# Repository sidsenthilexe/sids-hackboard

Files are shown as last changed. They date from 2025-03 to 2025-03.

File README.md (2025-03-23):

# Sid's Hackboard
My hackboard is pretty closely based on my current keyboard (Steelseries Apex 3 TKL) because it fits very well for what I need it to do. Probably could have optimized it more but ran out of time.                         
I'll probably make some keys macros especially the cluster around Delete.                   
It also includes a volume knob + a switch for play/pause, skip, and rewind.                         
This was actually way easier than hackpad because I now use KiCad and Fusion a lot more (even for other projects), but figuring out how to do the integrated plate was a bit annoying, and drafting the edges also took some figuring out.                      
Anyway I made a (hopefully) functional keyboard.                    

## Key Features:
* Standard TKL layout
* Plate with integrated case
* Magnetic lift bar - totally not copied from s76
* Volume knob
* Probably way too tall but I didn't bother to measure properly

## CAD/case:
M3 (M5? idek) bolts and heatset inserts are used to hold the 2 pieces together, and an integrated plate is used to hold the pcb.

## PCB:
A matrix is wired to prevent ghosting - the wiring took way too long. There are 84 total keys and one rotary encoder + switch, organized in 17 columns and 6 rows.

## Firmware:
KMK was used for the firmware, I still need to figure out how to implement the volume controls though.

## BOM:
|ITEM|QTY|PRICE|
|----|---|-----|
|Orpheus Pico|1|price|
|mx switches|qty|price|
|stabs|qty|price|
|encoder|qty|price|
|3x10x60mm Magnets|1 pack of 4|5.99|
|1N4148 diodes|qty|price|
|keycaps|qty|price|
|bolts|qty|price|
|heatset inserts|qty|price|

## Images:
Fully assembled:          
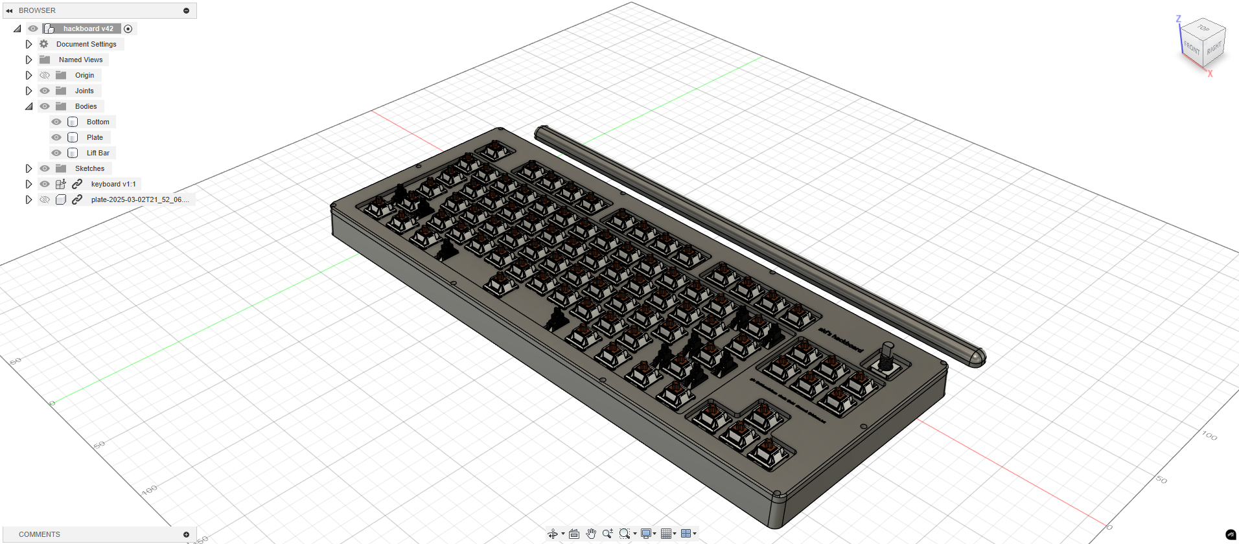
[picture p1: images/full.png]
               
Schematic:          
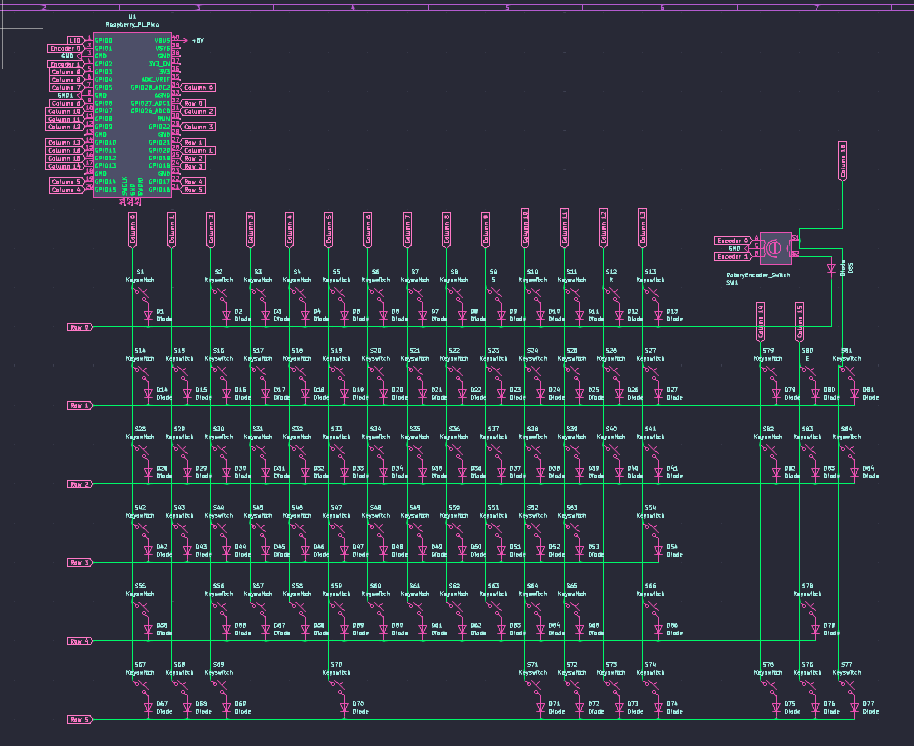
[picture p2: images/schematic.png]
                           
PCB:            
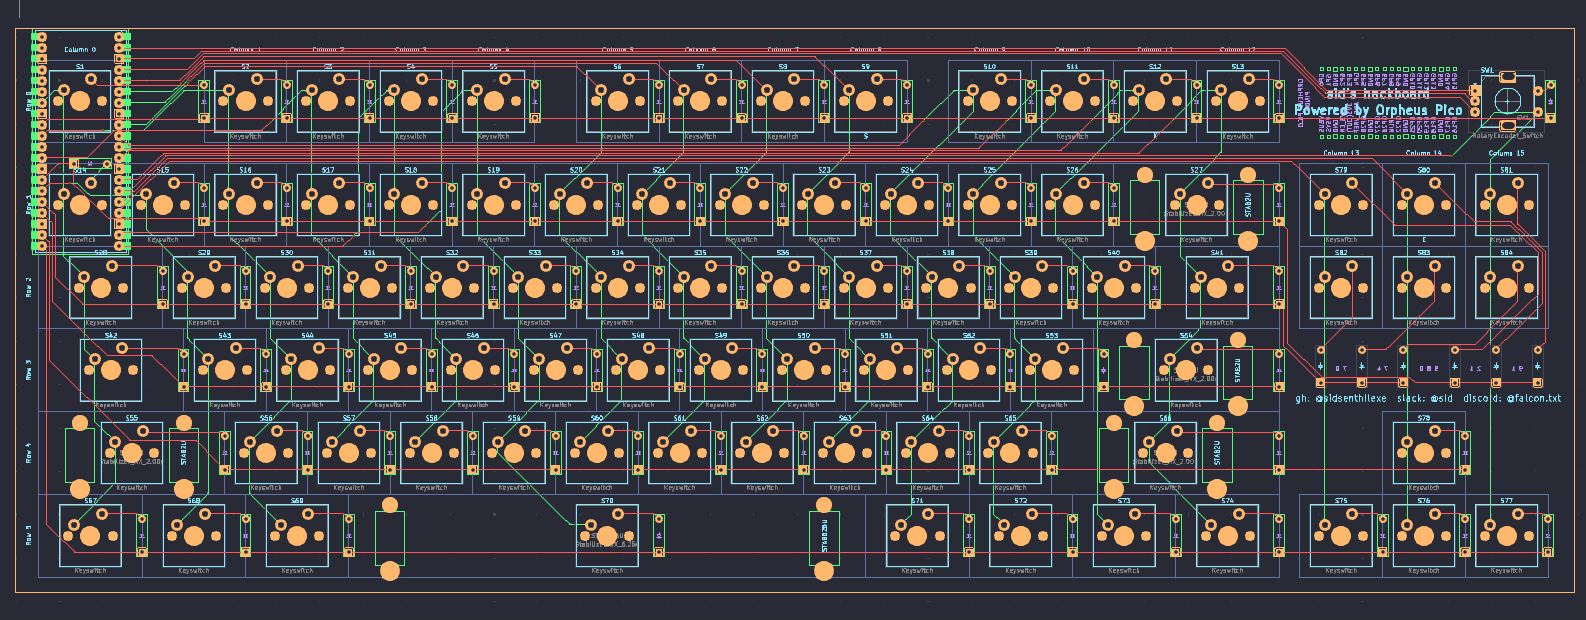
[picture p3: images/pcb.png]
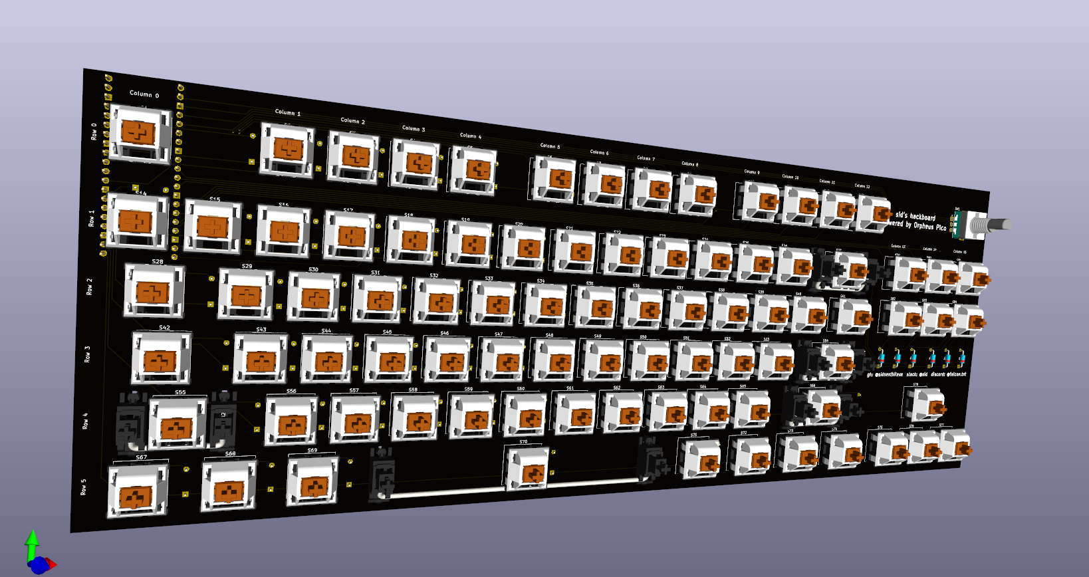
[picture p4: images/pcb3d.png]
                                                   
Case:                                                     
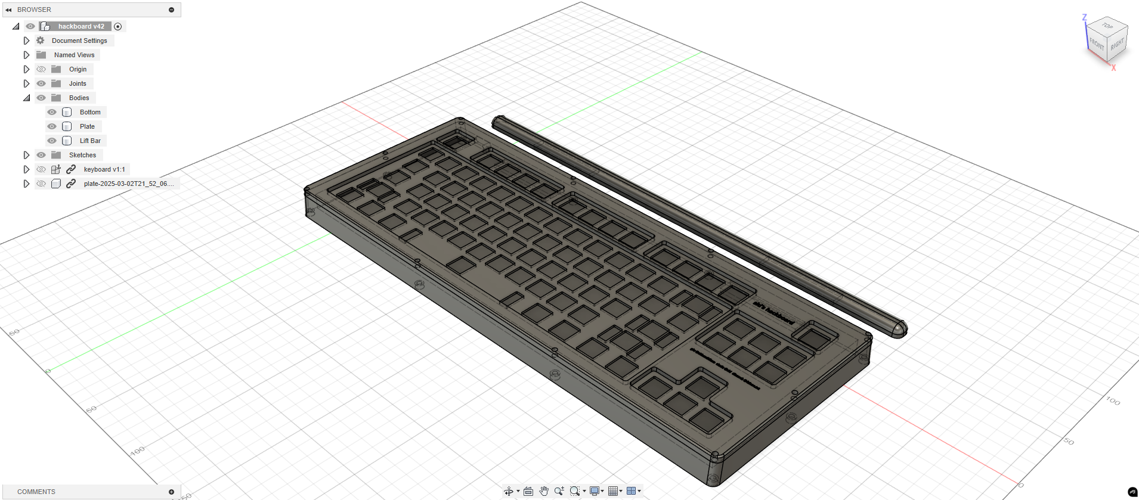
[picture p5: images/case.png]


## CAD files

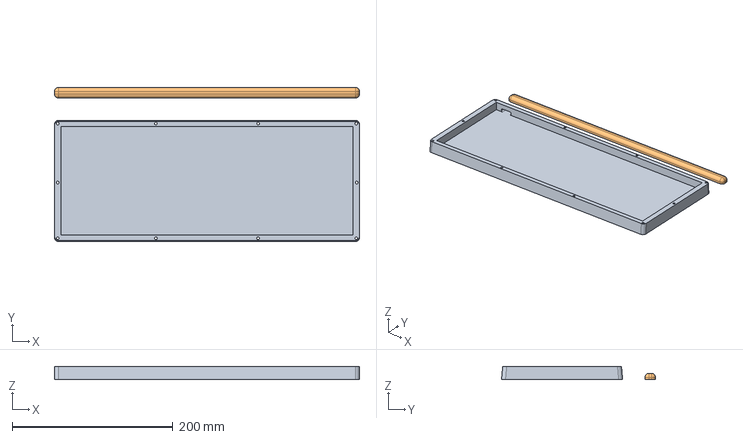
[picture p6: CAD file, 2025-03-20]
production/bottom_lift_bar.step
380.0 x 191.9 x 16.8 mm

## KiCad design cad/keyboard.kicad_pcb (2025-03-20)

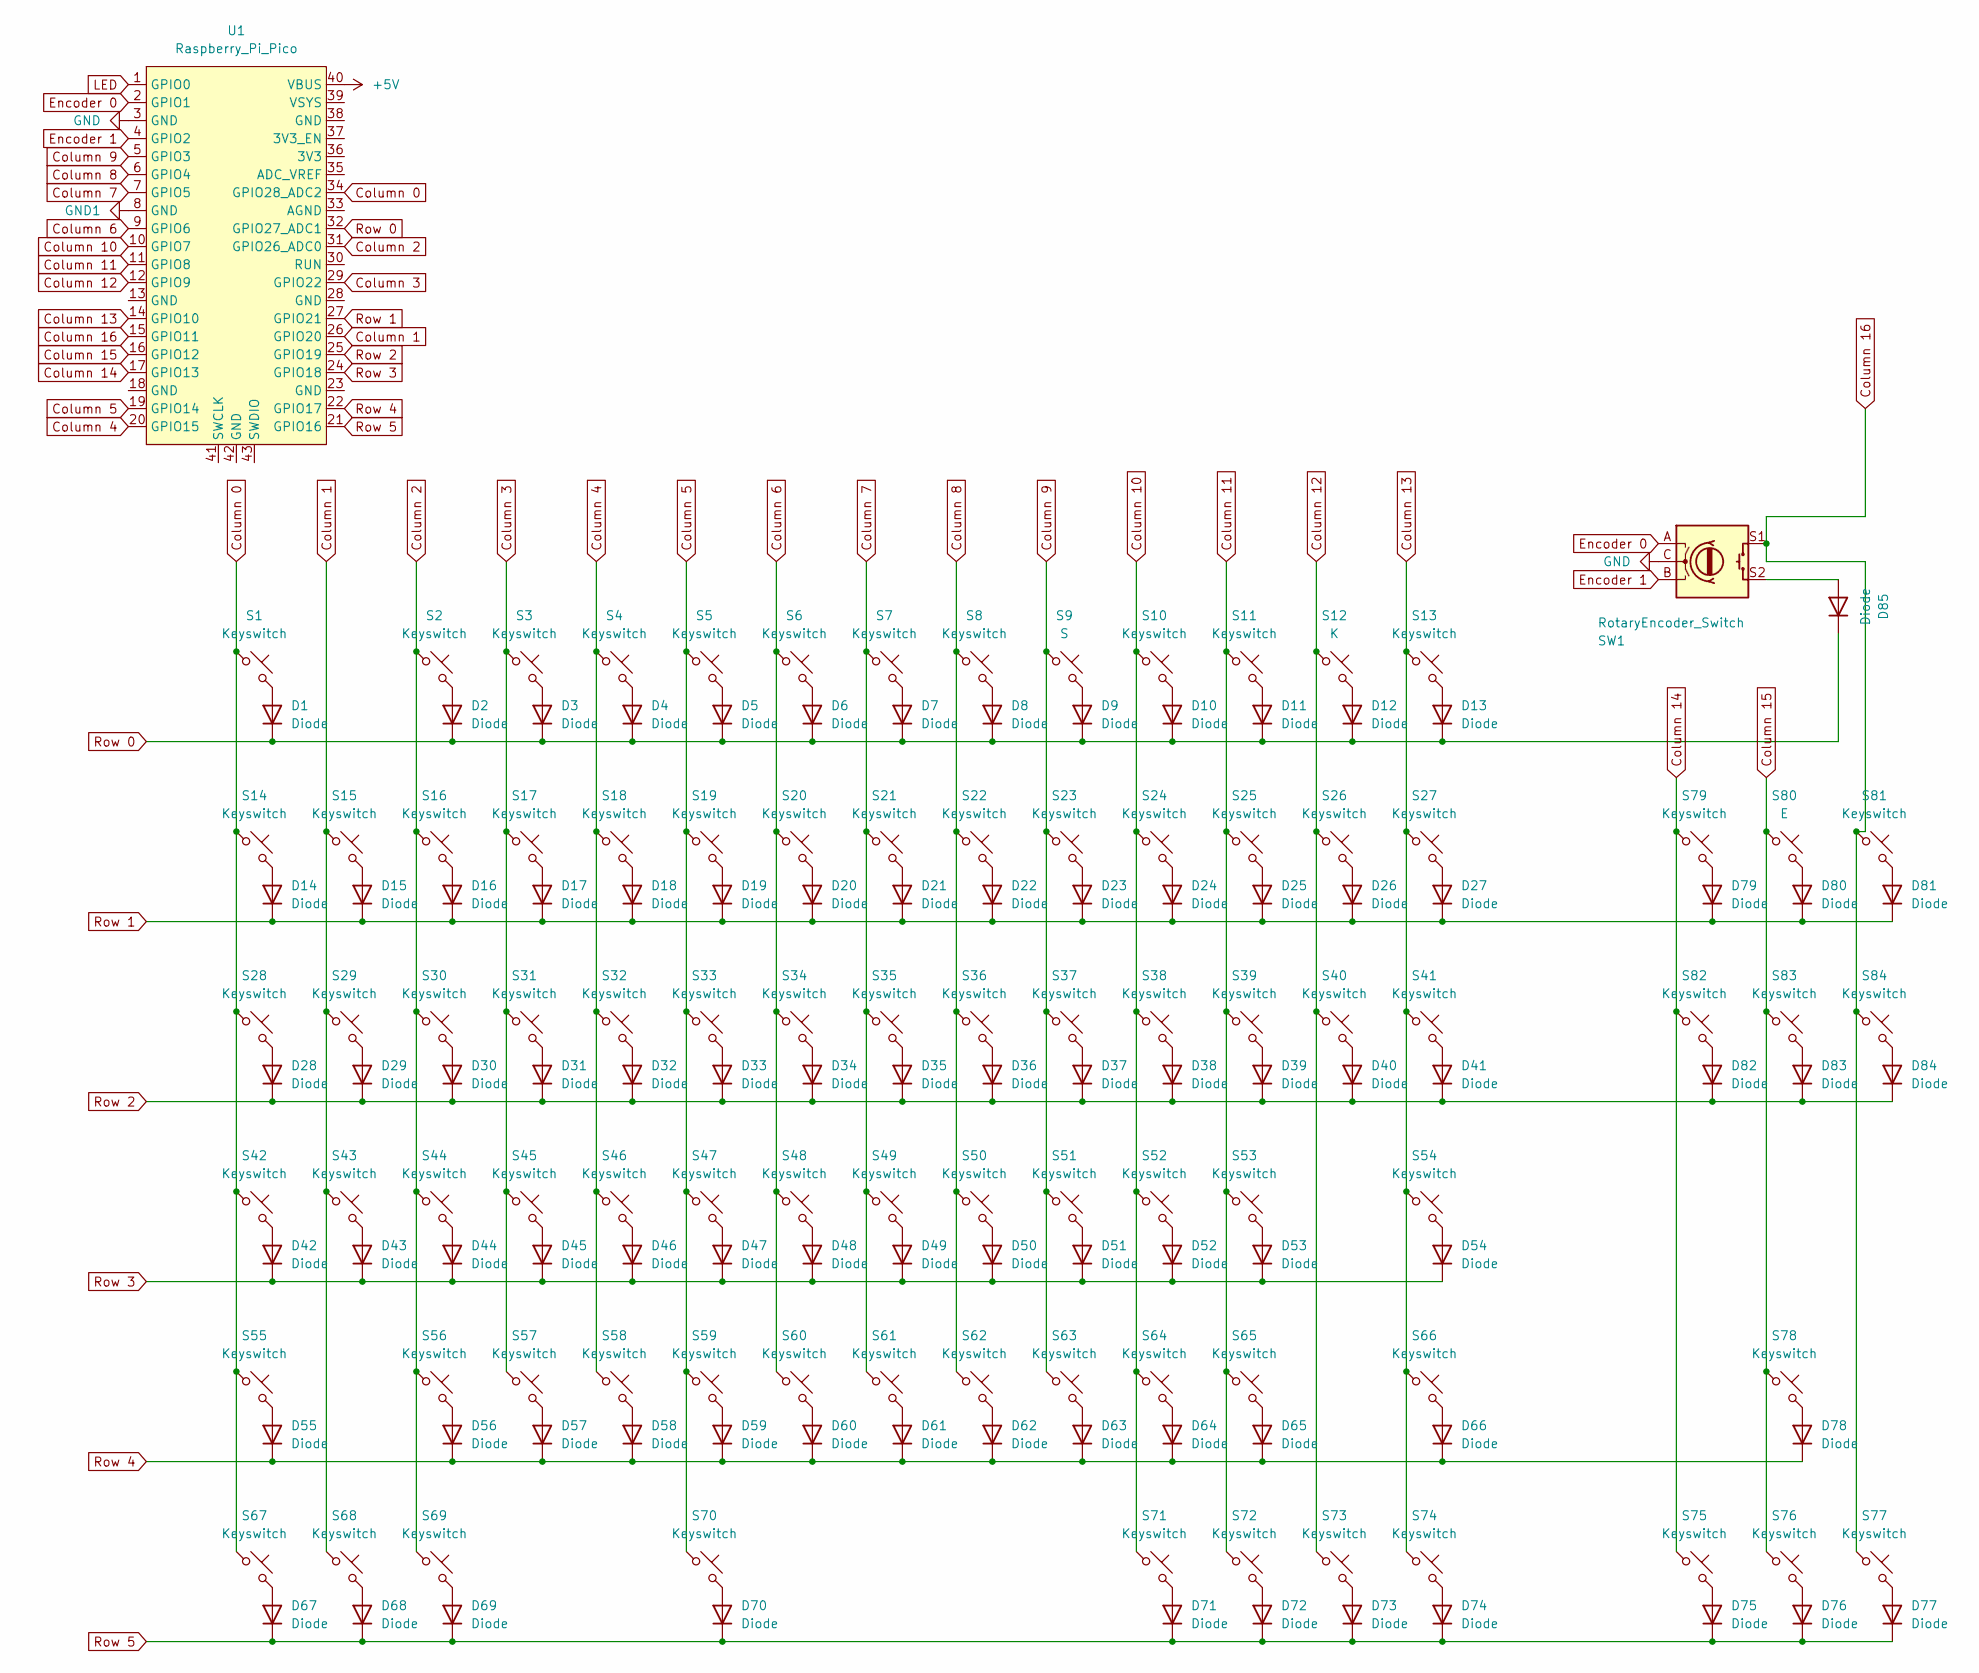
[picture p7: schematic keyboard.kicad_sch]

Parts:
D1, D2, D3, D4, D5, D6, D7, D8, D9, D10, D11, D12, D13, D14, D15, D16, D17, D18, D19, D20, D21, D22, D23, D24, D25, D26, D27, D28, D29, D30, D31, D32, D33, D34, D35, D36, D37, D38, D39, D40, D41, D42, D43, D44, D45, D46, D47, D48, D49, D50, D51, D52, D53, D54, D55, D56, D57, D58, D59, D60, D61, D62, D63, D64, D65, D66, D67, D68, D69, D70, D71, D72, D73, D74, D75, D76, D77, D78, D79, D80, D81, D82, D83, D84, D85: Diode; Diode_DO-35
S1, S2, S3, S4, S5, S6, S7, S8, S10, S11, S13, S14, S15, S16, S17, S18, S19, S20, S21, S22, S23, S24, S25, S26, S29, S30, S31, S32, S33, S34, S35, S36, S37, S38, S39, S40, S43, S44, S45, S46, S47, S48, S49, S50, S51, S52, S53, S56, S57, S58, S59, S60, S61, S62, S63, S64, S65, S75, S76, S77, S78, S79, S81, S82, S83, S84: Keyswitch; MX_PCB_1.00u
S9: S; MX_PCB_1.00u
S12: K; MX_PCB_1.00u
S27: Keyswitch; MX_PCB_2.00u
S28, S41: Keyswitch; MX_PCB_1.50u
S42: Keyswitch; MX_PCB_1.75u
S54, S55: Keyswitch; MX_PCB_2.25u
S66: Keyswitch; MX_PCB_2.75u
S67, S68, S69, S71, S72, S73, S74: Keyswitch; MX_PCB_1.25u
S70: Keyswitch; MX_PCB_6.25u
S80: E; MX_PCB_1.00u
SW1: RotaryEncoder_Switch; RotaryEncoder_Alps_EC11E-Switch_Vertical_H20mm
U1: Raspberry_Pi_Pico

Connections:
+5V: U1.40 (VBUS)
Column 0: S1.1, S14.1, S28.1, S42.1, S55.1, S67.1, U1.34 (GPIO28_ADC2)
Column 1: S15.1, S29.1, S43.1, S68.1, U1.26 (GPIO20)
Column 2: S2.1, S16.1, S30.1, S44.1, S56.1, S69.1, U1.31 (GPIO26_ADC0)
Column 3: S3.1, S17.1, S31.1, S45.1, S57.1, U1.29 (GPIO22)
Column 4: S4.1, S18.1, S32.1, S46.1, S58.1, U1.20 (GPIO15)
Column 5: S5.1, S19.1, S33.1, S47.1, S59.1, S70.1, U1.19 (GPIO14)
Column 6: S6.1, S20.1, S34.1, S48.1, S60.1, U1.9 (GPIO6)
Column 7: S7.1, S21.1, S35.1, S49.1, S61.1, U1.7 (GPIO5)
Column 8: S8.1, S22.1, S36.1, S50.1, S62.1, U1.6 (GPIO4)
Column 9: S9.1, S23.1, S37.1, S51.1, S63.1, U1.5 (GPIO3)
Column 10: S10.1, S24.1, S38.1, S52.1, S64.1, S71.1, U1.10 (GPIO7)
Column 11: S11.1, S25.1, S39.1, S53.1, S65.1, S72.1, U1.11 (GPIO8)
Column 12: S12.1, S26.1, S40.1, S73.1, U1.12 (GPIO9)
Column 13: S13.1, S27.1, S41.1, S54.1, S66.1, S74.1, U1.14 (GPIO10)
Column 14: S75.1, S79.1, S82.1, U1.17 (GPIO13)
Column 15: S76.1, S78.1, S80.1, S83.1, U1.16 (GPIO12)
Column 16: S77.1, S81.1, S84.1, SW1.S1, U1.15 (GPIO11)
Encoder 0: SW1.A, U1.2 (GPIO1)
Encoder 1: SW1.B, U1.4 (GPIO2)
GND: SW1.C, U1.3 (GND)
GND1: U1.8 (GND)
LED: U1.1 (GPIO0)
unnamed: D1.2 (A), S1.2
unnamed: D2.2 (A), S2.2
unnamed: D3.2 (A), S3.2
unnamed: D4.2 (A), S4.2
unnamed: D5.2 (A), S5.2
unnamed: D6.2 (A), S6.2
unnamed: D7.2 (A), S7.2
unnamed: D8.2 (A), S8.2
unnamed: D9.2 (A), S9.2
unnamed: D10.2 (A), S10.2
unnamed: D11.2 (A), S11.2
unnamed: D12.2 (A), S12.2
unnamed: D13.2 (A), S13.2
unnamed: D14.2 (A), S14.2
unnamed: D15.2 (A), S15.2
unnamed: D16.2 (A), S16.2
unnamed: D17.2 (A), S17.2
unnamed: D18.2 (A), S18.2
unnamed: D19.2 (A), S19.2
unnamed: D20.2 (A), S20.2
unnamed: D21.2 (A), S21.2
unnamed: D22.2 (A), S22.2
unnamed: D23.2 (A), S23.2
unnamed: D24.2 (A), S24.2
unnamed: D25.2 (A), S25.2
unnamed: D26.2 (A), S26.2
unnamed: D27.2 (A), S27.2
unnamed: D28.2 (A), S28.2
unnamed: D29.2 (A), S29.2
unnamed: D30.2 (A), S30.2
unnamed: D31.2 (A), S31.2
unnamed: D32.2 (A), S32.2
unnamed: D33.2 (A), S33.2
unnamed: D34.2 (A), S34.2
unnamed: D35.2 (A), S35.2
unnamed: D36.2 (A), S36.2
unnamed: D37.2 (A), S37.2
unnamed: D38.2 (A), S38.2
unnamed: D39.2 (A), S39.2
unnamed: D40.2 (A), S40.2
unnamed: D41.2 (A), S41.2
unnamed: D42.2 (A), S42.2
unnamed: D43.2 (A), S43.2
unnamed: D44.2 (A), S44.2
unnamed: D45.2 (A), S45.2
unnamed: D46.2 (A), S46.2
unnamed: D47.2 (A), S47.2
unnamed: D48.2 (A), S48.2
unnamed: D49.2 (A), S49.2
unnamed: D50.2 (A), S50.2
unnamed: D51.2 (A), S51.2
unnamed: D52.2 (A), S52.2
unnamed: D53.2 (A), S53.2
unnamed: D54.2 (A), S54.2
unnamed: D55.2 (A), S55.2
unnamed: D56.2 (A), S56.2
unnamed: D57.2 (A), S57.2
unnamed: D58.2 (A), S58.2
unnamed: D59.2 (A), S59.2
unnamed: D60.2 (A), S60.2
unnamed: D61.2 (A), S61.2
unnamed: D62.2 (A), S62.2
unnamed: D63.2 (A), S63.2
unnamed: D64.2 (A), S64.2
unnamed: D65.2 (A), S65.2
unnamed: D66.2 (A), S66.2
unnamed: D67.2 (A), S67.2
unnamed: D68.2 (A), S68.2
unnamed: D69.2 (A), S69.2
unnamed: D70.2 (A), S70.2
unnamed: D71.2 (A), S71.2
unnamed: D72.2 (A), S72.2
unnamed: D73.2 (A), S73.2
unnamed: D74.2 (A), S74.2
unnamed: D75.2 (A), S75.2
unnamed: D76.2 (A), S76.2
unnamed: D77.2 (A), S77.2
unnamed: D78.2 (A), S78.2
unnamed: D79.2 (A), S79.2
unnamed: D80.2 (A), S80.2
unnamed: D81.2 (A), S81.2
unnamed: D82.2 (A), S82.2
unnamed: D83.2 (A), S83.2
unnamed: D84.2 (A), S84.2
unnamed: D85.2 (A), SW1.S2
Row 0: D1.1 (K), D2.1 (K), D3.1 (K), D4.1 (K), D5.1 (K), D6.1 (K), D7.1 (K), D8.1 (K), D9.1 (K), D10.1 (K), D11.1 (K), D12.1 (K), D13.1 (K), D85.1 (K), U1.32 (GPIO27_ADC1)
Row 1: D14.1 (K), D15.1 (K), D16.1 (K), D17.1 (K), D18.1 (K), D19.1 (K), D20.1 (K), D21.1 (K), D22.1 (K), D23.1 (K), D24.1 (K), D25.1 (K), D26.1 (K), D27.1 (K), D79.1 (K), D80.1 (K), D81.1 (K), U1.27 (GPIO21)
Row 2: D28.1 (K), D29.1 (K), D30.1 (K), D31.1 (K), D32.1 (K), D33.1 (K), D34.1 (K), D35.1 (K), D36.1 (K), D37.1 (K), D38.1 (K), D39.1 (K), D40.1 (K), D41.1 (K), D82.1 (K), D83.1 (K), D84.1 (K), U1.25 (GPIO19)
Row 3: D42.1 (K), D43.1 (K), D44.1 (K), D45.1 (K), D46.1 (K), D47.1 (K), D48.1 (K), D49.1 (K), D50.1 (K), D51.1 (K), D52.1 (K), D53.1 (K), D54.1 (K), U1.24 (GPIO18)
Row 4: D55.1 (K), D56.1 (K), D57.1 (K), D58.1 (K), D59.1 (K), D60.1 (K), D61.1 (K), D62.1 (K), D63.1 (K), D64.1 (K), D65.1 (K), D66.1 (K), D78.1 (K), U1.22 (GPIO17)
Row 5: D67.1 (K), D68.1 (K), D69.1 (K), D70.1 (K), D71.1 (K), D72.1 (K), D73.1 (K), D74.1 (K), D75.1 (K), D76.1 (K), D77.1 (K), U1.21 (GPIO16)

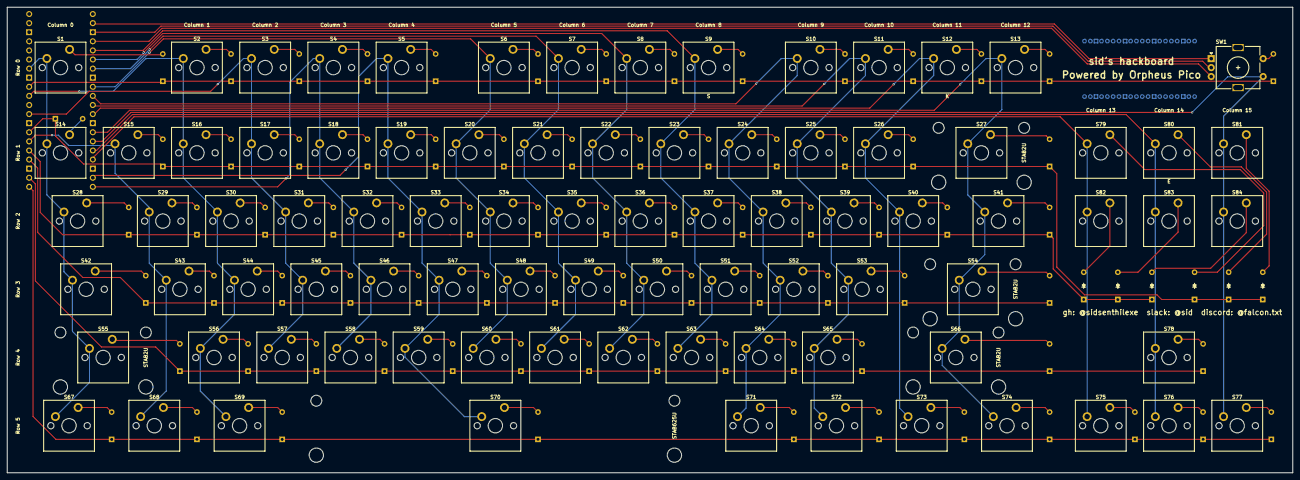
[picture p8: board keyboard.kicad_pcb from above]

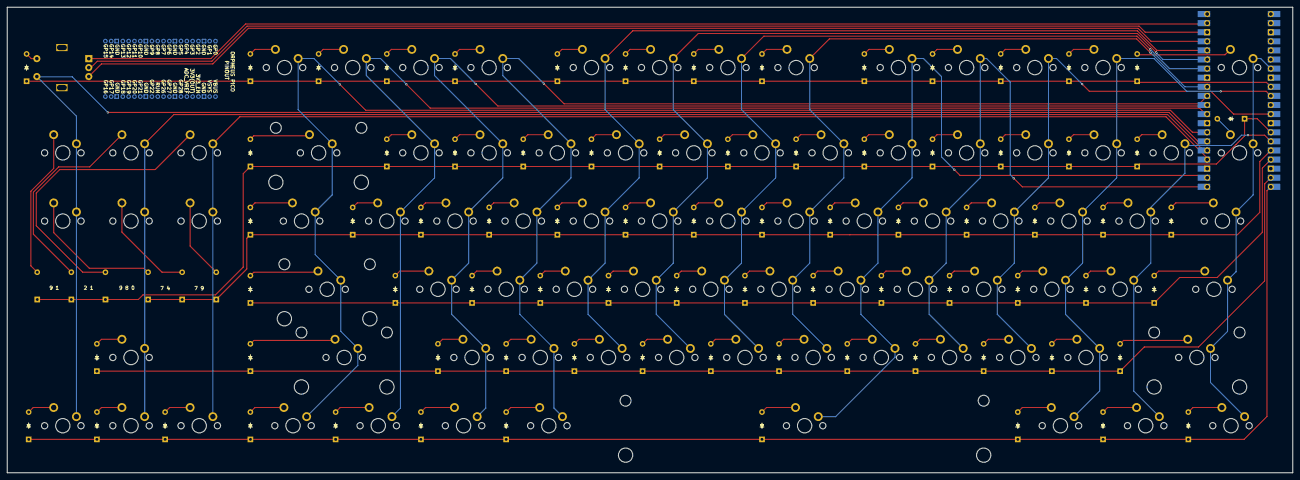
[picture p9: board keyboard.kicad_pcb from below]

Board: 2 copper layers, 359.0 x 130.0 mm, 176 parts (80 on the bottom side), 111 nets.

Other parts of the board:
STAB2U, STAB2U#2, STAB2U#3, STAB2U#4: Stabilizer_MX_2.00u
STAB625U: Stabilizer_MX_6.25u

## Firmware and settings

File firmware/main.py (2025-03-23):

import board

from kmk.kmk_keyboard import KMKKeyboard
from kmk.keys import KC
from kmk.scanners import DiodeOrientation

keyboard = KMKKeyboard()

keyboard.col_pins = (board.GP28, board.GP20, board.GP26, board.GP22, board.GP15, board.GP14, board.GP6, board.GP5, board.GP4, board.GP3, board.GP7, board.GP8, board.GP9, board.GP10, board.GP13, board.GP12, board.GP11)
keyboard.row_pins = (board.GP27, board.GP21, board.GP19, board.GP18, board.GP17, board.GP16)
keyboard.diode_orientation = DiodeOrientation.COL2ROW

keyboard.keymap = [
    [
        
        KC.ESC, KC.F1, KC.F2, KC.F3, KC.F4, KC.F5, KC.F6, KC.F7, KC.F8, KC.F9, KC.F10, KC.F11, KC.F12,
        KC.GRAVE, KC.N1, KC.N2, KC.N3, KC.N4, KC.N5, KC.N6,KC.N7, KC.N8, KC.N9, KC.N0, KC.MINUS, KC.EQUAL, KC.BACKSPACE, KC.INS, KC.HOME, KC.PGUP,
        KC.TAB, KC.Q, KC.W, KC.E, KC.R, KC.T, KC.Y, KC.U, KC.I, KC.O, KC.P, KC.LBRACKET, KC.RBRACKET, KC.BSLASH, KC.DEL, KC.END, KC.PGDN,
        KC.CAPS, KC.A, KC.S, KC.D, KC.F, KC.G, KC.H, KC.J, KC.K, KC.L, KC.SEMICOLON, KC.QUOTE, KC.ENTER,
        KC.LSFT, KC.Z, KC.X, KC.C, KC.V, KC.B, KC.N, KC.M, KC.COMMA, KC.DOT, KC.SLASH, KC.RSFT, KC.UP
        KC.LCTL, KC.LGUI, KC.LALT, KC.SPC, KC.RALT, KC.RGUI, KC.APP, KC.RCTL, KC.LEFT, KC.DOWN, KC.RIGHT
    ]
]

if __name__ == '__main__':
    keyboard.go()
